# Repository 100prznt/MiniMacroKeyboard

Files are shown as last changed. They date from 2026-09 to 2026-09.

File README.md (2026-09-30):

# Mini Macro Keyboard (Raspberry Pi Pico)






Eine kleine USB-Makro-Tastatur auf Basis eines Raspberry Pi Pico, programmiert in
CircuitPython. Der Pico meldet sich am PC als Composite-HID-Gerät (Tastatur +
Maus gleichzeitig) und macht auf einer selbstgebauten 3-Taster-Platine ein paar
wiederkehrende Eingaben und eine kleine Anwesenheitssimulation überflüssig.

Ein Windows-Companion-Programm in C# (`MacroKeyboardSync/`) läuft im Hintergrund
und meldet dem Pico über einen zweiten USB-CDC-Kanal Uhrzeit, die aktuell aktive
Anwendung und den Sperrstatus des PCs.

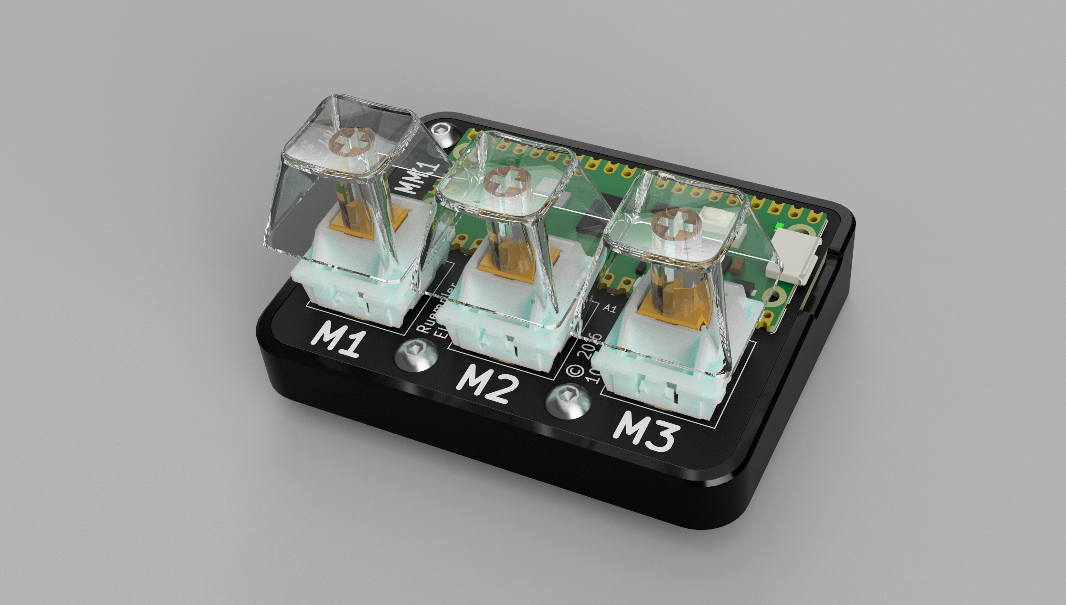
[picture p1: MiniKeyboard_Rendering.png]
MMK1 Rendering


## Funktionen

Die Platine hat drei Taster (M1–M3), alle gegen GND schaltend:

| Taste | Aktion |
|---|---|
| **M1** | Beim Loslassen: zweizeiliger TODO-Kommentar mit Name/Kürzel und aktuellem Zeitstempel, z. B. `// Mustermann, Max (MM/Abt1) 23.09.2026 10:23:34` gefolgt von einer leeren Kommentarzeile `// ` (Zeilenumbruch per Shift+Enter) |
| **M2** | Beim Loslassen: Text `M2` (Platzhalter, frei anpassbar) |
| **M3** | Kurzer Druck: gibt beim Loslassen die aktuell aktive Anwendung aus (siehe unten). Langer Druck (≥ 0,5 s): schaltet den Mausjiggler sofort um, ohne auf das Loslassen zu warten |
| **M1 + M3** (gleichzeitig) | Löscht per Backspace das letzte Zeichen im aktiven Feld, wartet kurz und gibt dann einen hinterlegten Text (`TEXT_M4`) + Enter aus – **nur** wenn entweder eine bestimmte Anwendung (in `code.py` festgelegt) im Vordergrund ist oder der PC gerade gesperrt ist. `M2` bleibt davon unbeteiligt |

**Mausjiggler:** Solange aktiv (Standard: direkt nach dem Einschalten), bewegt
sich der Mauszeiger alle 25 Sekunden minimal, um Bildschirmschoner/Abwesend-Status
(z. B. in Teams) zu verhindern. Die Onboard-LED pulsiert währenddessen in einem
Herzschlag-Muster (zwei Auf-/Abdimm-Pulse, kurze Pause, dann eine längere Pause).

**Status-LEDs:** Drei adressierbare RGB-LEDs (LTST-E683CEGBW) unter den Tastern,
in Reihe an GPIO18 über einen BSS138-Levelshifter angeschlossen, zeigen den
aktuellen Zustand an:
- **Aktive Anwendung:** alle drei LEDs leuchten in einer festen Farbe je nach
  `WIN:`-Tag – z. B. Lila für Visual Studio, Orange für KiCad, Grün für den
  KiCad-PCB-Editor, Rot für Opera, Weiß für den Explorer, Blau für Outlook/Teams,
  Lila für GitHub Desktop. Unbekannte Anwendungen zeigen ein gedimmtes Grau
  (`DEFAULT`).
- **VPN-Client aktiv:** die LEDs blinken abwechselnd Rot/Blau, wie ein
  US-Polizeiauto.
- **PC gesperrt:** rotes Lauflicht über die drei LEDs (Knight-Rider-/KITT-Effekt),
  zusätzlich gedimmt gegenüber den übrigen Zuständen. Hat Vorrang vor allen
  anderen Anzeigen.

Die Helligkeit aller Status-LEDs ist über die Konstante `MAX_BRIGHTNESS` in
`code.py` gedeckelt (Standard: 75 %).

**Sync mit dem PC:** Die Companion-App erkennt über die USB-Vendor-ID automatisch
den passenden COM-Port und sendet dem Pico:
- `TIME:` alle 5 Minuten (stellt die Software-RTC des Pico)
- `WIN:` bei jedem Wechsel der aktiven Anwendung (VS, VS Code, KiCad, KiCad-PCB-Editor,
  Opera, Explorer, Outlook, GitHub Desktop, Teams, VPN-Client – alles andere
  als `DEFAULT`)
- `LOCK:` bei Sperren/Entsperren sowie als Heartbeat alle 15 Sekunden, damit
  der Pico eine tote Verbindung erkennt

Ohne aktuelle Nachricht vom PC (z. B. direkt nach einem Neustart, bevor die
Companion-App läuft) geht der Pico sicherheitshalber von "gesperrt" aus.

## Hardware

- Raspberry Pi Pico
- Eigene Taster-Platine mit 3 Tastern gegen GND:
  - M1 → GPIO17
  - M2 → GPIO26
  - M3 → GPIO28
- 3x adressierbare RGB-LED LTST-E683CEGBW (in Reihe), Datenleitung an GPIO18
  über einen BSS138-Levelshifter

### CAD-Ansichten

| Von oben | Von rechts |
|---|---|
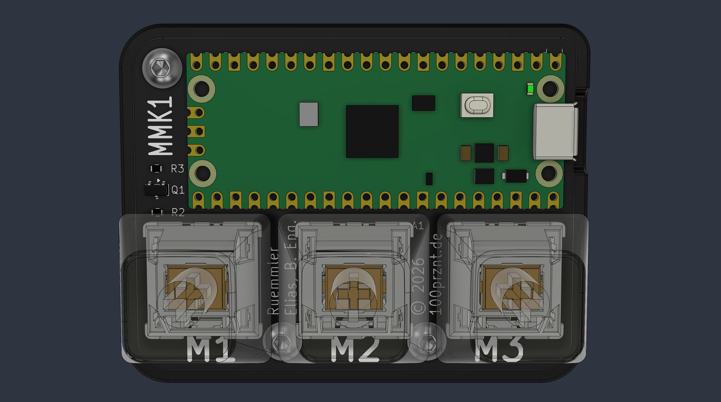
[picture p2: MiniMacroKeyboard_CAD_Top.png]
CAD-Ansicht von oben
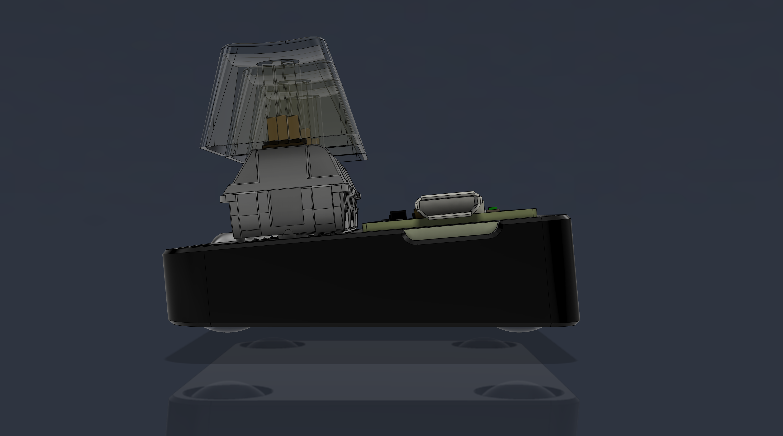
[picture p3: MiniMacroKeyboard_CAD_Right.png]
CAD-Ansicht von rechts
|  |  |

*Rechts:* Auf der Unterseite des 3D-gedruckten Rahmens sorgen 4 Gummipuffer für einen sicheren Stand.

### Erster Hardwareaufbau

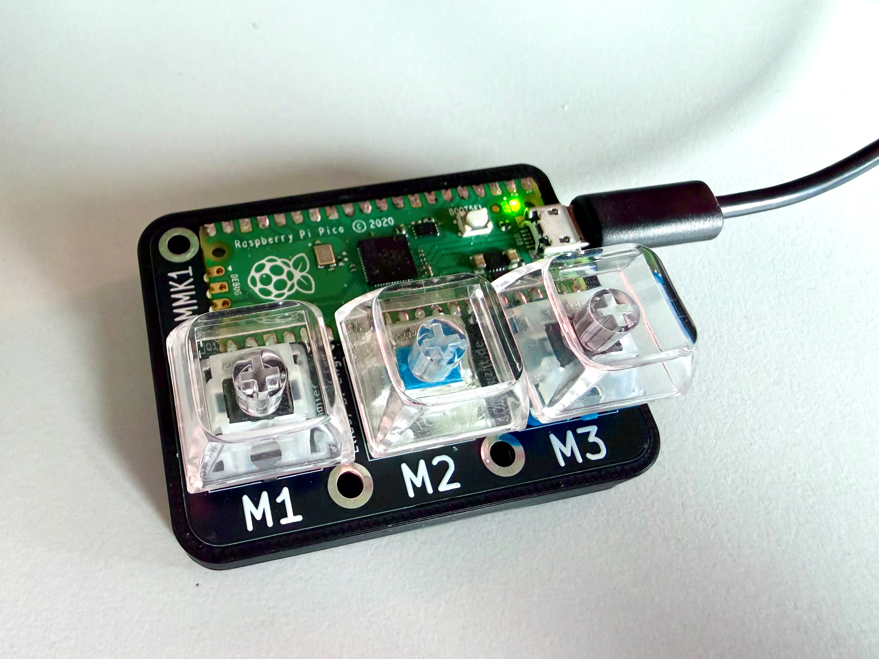
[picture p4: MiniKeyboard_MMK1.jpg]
Erster Hardwareaufbau


## Repo-Struktur

```
src/boot.py       Aktiviert den zweiten USB-CDC-Datenkanal (usb_cdc.data)
src/code.py       Hauptprogramm: Taster-Logik, HID-Ausgabe, Mausjiggler, Status-LEDs, Sync
src/macros.py.template  Vorlage fuer macros.py (TEXT_M2, TEXT_M4, TODO_SIGNATURE)
src/lib/          Benötigte CircuitPython-Bibliotheken (adafruit_hid, neopixel, dt. Tastaturlayout)
install/          CircuitPython-UF2 für den Pico (de_DE)
MacroKeyboardSync/ Windows-Companion-App (C#, .NET 8)
```

## Einrichtung (Pico)

1. [CircuitPython](https://circuitpython.org/board/raspberry_pi_pico/) auf den
   Pico flashen (die passende UF2-Datei liegt auch in `install/`).
2. Den Ordner `src/lib/` in den Ordner `lib/` auf dem `CIRCUITPY`-Laufwerk
   kopieren. Er enthält bereits alle benötigten Bibliotheken, sie müssen
   nicht separat heruntergeladen werden:
   - `adafruit_hid/` aus dem
     [Adafruit CircuitPython HID](https://github.com/adafruit/Adafruit_CircuitPython_HID)
   - `neopixel.mpy` aus dem
     [Adafruit CircuitPython Bundle](https://circuitpython.org/libraries)
     (steuert die drei Status-LEDs)
   - `keyboard_layout_win_de.py` und `keycode_win_de.py` (deutsches
     Tastaturlayout) aus
     [Neradoc/Circuitpython_Keyboard_Layouts](https://github.com/Neradoc/Circuitpython_Keyboard_Layouts)

   Die zugehörigen Lizenzen liegen als `LICENSE-*` daneben (beide MIT). Wer
   lieber aktuelle Versionen nutzt, kann sie stattdessen selbst aus dem
   [Adafruit CircuitPython Bundle](https://circuitpython.org/libraries) bzw.
   dem Neradoc-Repo holen.
3. `boot.py` und `code.py` aus `src/` auf das `CIRCUITPY`-Laufwerk kopieren.
4. `src/macros.py.template` nach `macros.py` kopieren (muss neben `code.py`
   liegen) und an die eigenen Texte anpassen (Name/Kürzel für M1, Text für
   die M1+M3-Combo). `macros.py` ist bewusst per `.gitignore` ausgeschlossen,
   damit persönliche Texte nicht versehentlich committet werden.

## Einrichtung (Companion-App)

1. `MacroKeyboardSync/` mit .NET 8 SDK bauen (`dotnet build` bzw. Visual
   Studio).
2. Die App beim Windows-Systemstart starten lassen (z. B. Autostart-Ordner
   oder Aufgabenplanung) – sie läuft ohne Konsolenfenster im Hintergrund.
3. Erkannte Anwendungen sind in der `KnownApps`-Dictionary in `Program.cs`
   hinterlegt und lassen sich dort um weitere Prozessnamen ergänzen. Läuft
   eine Anwendung (wie z. B. KiCad) bei dir komplett unter einem einzigen
   Prozess, wird in `GetActiveAppTag()` zusätzlich der Fenstertitel
   ausgewertet, um z. B. den PCB-Editor separat zu erkennen – Titeltext ggf.
   an die eigene Sprachversion anpassen.

## Hinweis zur M1+M3-Combo

Der bei `TEXT_M4` hinterlegte Text ist bei mir persönlich durch ein Passwort
ersetzt, das nur bei passender Anwendung bzw. gesperrtem PC getippt wird. Wer
das Repo als Vorlage nutzt: Der Wert liegt aktuell als Klartext in `macros.py`
auf dem Flash-Speicher des Pico – bei physischem Zugriff auf das Gerät ist er
auslesbar. Für den privaten Gebrauch an einem einzelnen, vertrauenswürdigen
Rechner ist das ein bewusst akzeptiertes Risiko, kein Ersatz für einen echten
Passwortmanager.

## Lizenz

Dieses Projekt steht unter der [MIT-Lizenz](LICENSE).

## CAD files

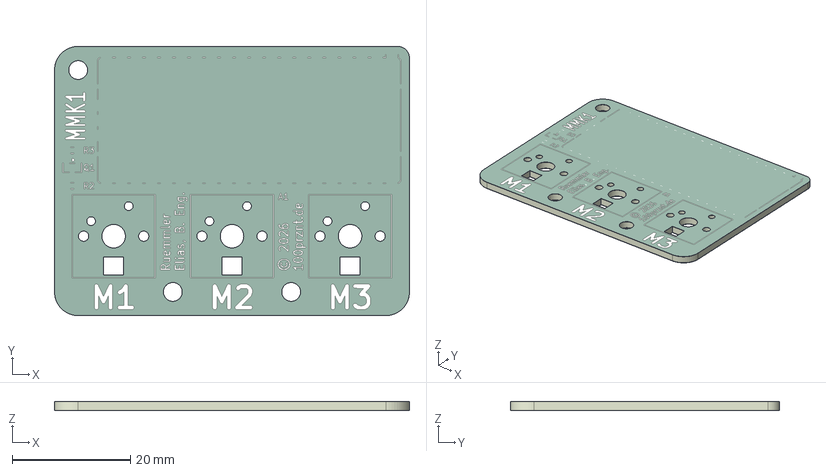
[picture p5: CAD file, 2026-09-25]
hardware/MiniMacroKeyboard/MiniMacroKeyboard.step
60.0 x 45.5 x 1.66 mm
Min7E8_silkscreen x 2
Min7E8_soldermask x 2
Min7E8_PCB

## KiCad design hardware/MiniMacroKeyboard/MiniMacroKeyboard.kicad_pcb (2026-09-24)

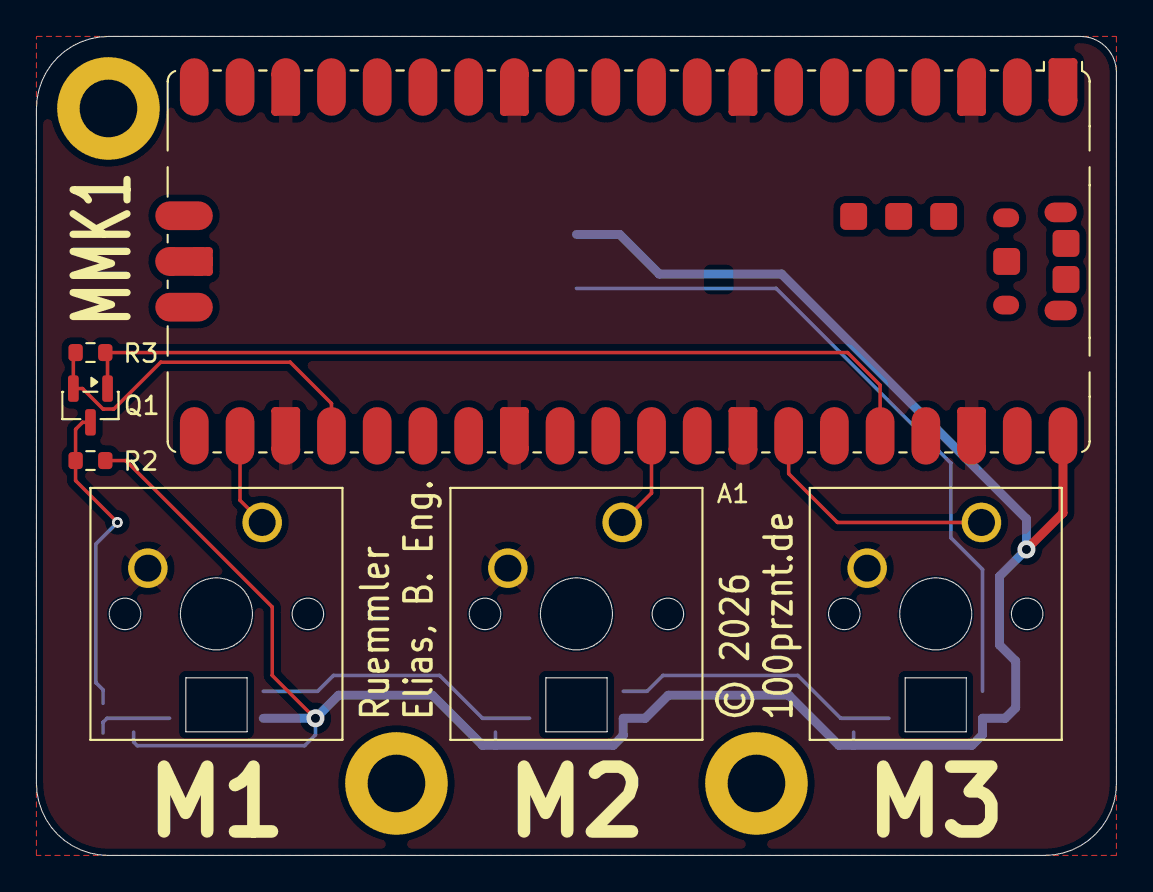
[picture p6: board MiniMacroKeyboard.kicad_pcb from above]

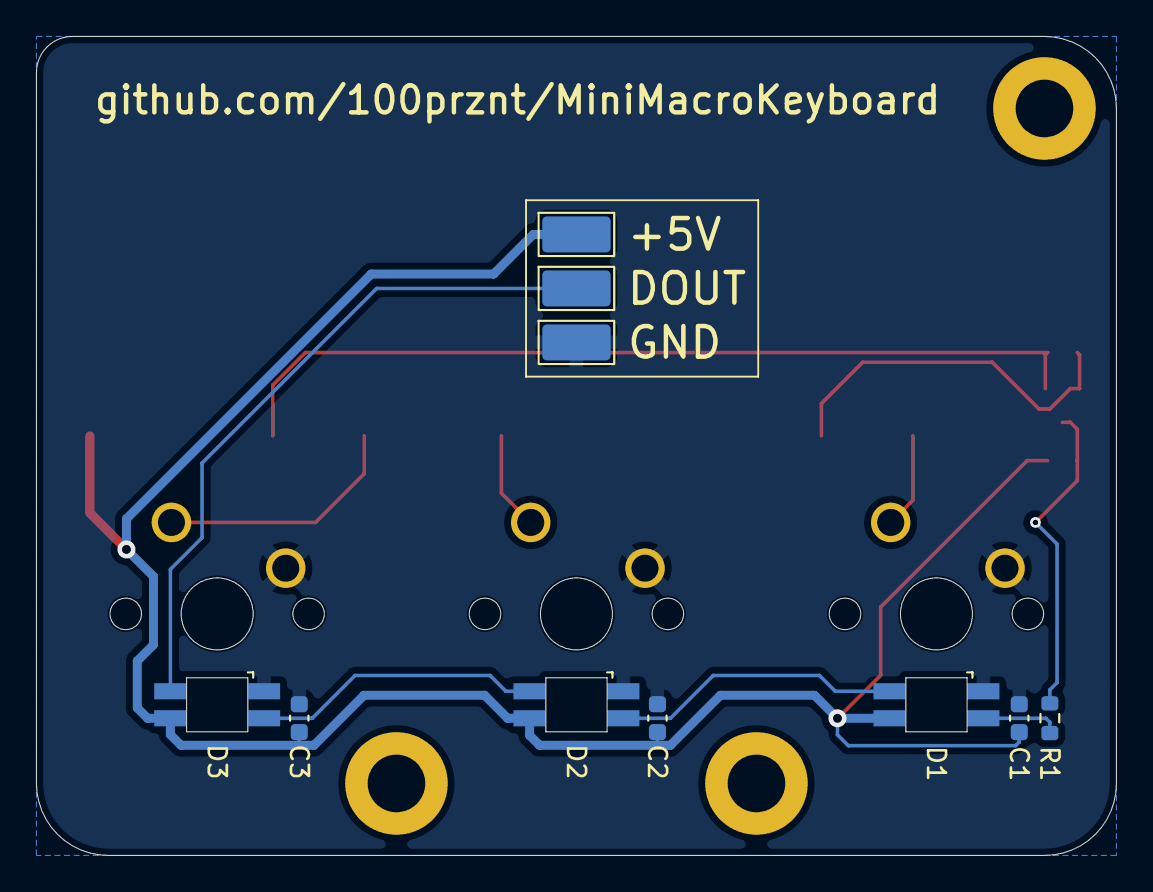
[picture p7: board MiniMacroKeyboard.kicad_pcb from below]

Board: 2 copper layers, 60.0 x 45.5 mm, 14 parts (7 on the bottom side), 12 nets.

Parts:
A1: RaspberryPi_Pico; RaspberryPi_Pico_SMD
C1, C2, C3: C; C_0603_1608Metric
M1, M2, M3: CherryMX_LTST-A683CEGBW; CherryMX_1.00u_PCB_LTST-A683CEGBW
Q1: BSS138; SOT-23
R1: 330R; R_0603_1608Metric
R2, R3: 10K; R_0603_1608Metric
TP1, TP2, TP3: TestPoint; TestPoint_Keystone_5019_Miniature

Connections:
+3.3V: A1.36 (3V3), Q1.1 (G), R3.2
+5V: A1.40 (VBUS), C1.1, C2.1, C3.1, M1.6 (VDD), M2.6 (VDD), M3.6 (VDD), R2.2, TP3.1 (1_1)
GNDD: A1.3 (GND), A1.8 (GND), A1.13 (GND), A1.18 (GND), A1.23 (GND), A1.28 (GND), A1.33 (AGND), A1.38 (GND), A1.D2 (GND), C1.2, C2.2, C3.2, M1.1, M1.3 (VSS), M2.1, M2.3 (VSS), M3.1, M3.3 (VSS), TP2.1 (1_1)
M1: A1.22 (GPIO17), M1.2
M2: A1.31 (GPIO26_ADC0), M2.2
M3: A1.34 (GPIO28_ADC2), M3.2
unnamed: A1.24 (GPIO18), Q1.2 (S), R3.1
unnamed: M1.4 (DIN), R1.1
unnamed: M1.5 (DOUT), M2.4 (DIN)
unnamed: M2.5 (DOUT), M3.4 (DIN)
unnamed: M3.5 (DOUT), TP1.1 (1_1)
unnamed: Q1.3 (D), R1.2, R2.1

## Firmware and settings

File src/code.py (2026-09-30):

import time
import board
import digitalio
import pwmio
import neopixel
import usb_hid
import usb_cdc
import rtc

from adafruit_hid.keyboard import Keyboard
from keyboard_layout_win_de import KeyboardLayout
from adafruit_hid.keycode import Keycode
from adafruit_hid.mouse import Mouse

from macros import TEXT_M2, TEXT_M4, TODO_SIGNATURE

kbd = Keyboard(usb_hid.devices)
layout = KeyboardLayout(kbd)
mouse = Mouse(usb_hid.devices)

# --- Taster-PCB: alle drei Taster schalten gegen GND ---
SWITCH_M1 = board.GP17
SWITCH_M2 = board.GP26
SWITCH_M3 = board.GP28

def make_switch(pin):
    io = digitalio.DigitalInOut(pin)
    io.direction = digitalio.Direction.INPUT
    io.pull = digitalio.Pull.UP   # gegen GND -> Pull-Up, gedrueckt = LOW
    return io

m1 = make_switch(SWITCH_M1)
m2 = make_switch(SWITCH_M2)
m3 = make_switch(SWITCH_M3)

# --- RGB-Status-LEDs: 3x LTST-E683CEGBW in Reihe an GPIO18 (ueber BSS138-Levelshifter) ---
# Alle drei LEDs zeigen gemeinsam die aktuell aktive Anwendung per Farbe an,
# ausser bei Sonderfaellen (VPN-Blinken, PC gesperrt -> Lauflicht).
# Falls die Farben vertauscht wirken, pixel_order=neopixel.RGB statt GRB testen.
LED_DATA_PIN = board.GP18
LED_COUNT = 3
MAX_BRIGHTNESS = 0.65   # 0.0-1.0, globale Helligkeitsgrenze fuer alle Status-LEDs

pixels = neopixel.NeoPixel(
    LED_DATA_PIN, LED_COUNT, brightness=MAX_BRIGHTNESS, auto_write=False,
    pixel_order=neopixel.RGB,
)

# Farbe je aktiver Anwendung (WIN:-Tag von der Companion-App, siehe check_serial())
APP_COLORS = {
    "VS":        (150, 0, 200),   # Visual Studio: kraeftiges Lila (wie das VS-Icon)
    "VSCODE":    (0, 122, 204),   # Visual Studio Code: Blau
    "KICAD":     (255, 80, 0),   # KiCad (Projektmanager/Schaltplan): Orange
    "KICAD_PCB": (40, 170, 0),    # KiCad PCB-Editor (Pcbnew): Gruen
    "OPERA":     (255, 0, 0),     # Opera: Rot
    "EXPLORER":  (255, 255, 255), # Explorer: Weiss
    "OUTLOOK":   (15, 15, 240),   # Outlook: Blau (wie das Outlook-Logo)
    "GITHUB":    (110, 0, 200),   # GitHub: Lila (wie das GitHub-Logo)
    "TEAMS":     (30, 50, 235),   # Teams: kraeftiges Blau (wie das Teams-Logo)
    "DEFAULT":   (20, 20, 20),
}

# VPN aktiv: rot/blau blinkend, wie ein US-Polizeiauto
VPN_FLASH_COLOR_A = (255, 0, 0)
VPN_FLASH_COLOR_B = (0, 0, 255)
VPN_FLASH_INTERVAL = 0.15    # Sekunden je Farbphase

# PC gesperrt: rotes Lauflicht (Knight-Rider/KITT-Scanner) ueber die 3 LEDs, gedimmt
LOCK_SCAN_COLOR = (255, 0, 0)
LOCK_SCAN_INTERVAL = 0.24          # Sekunden je Schritt
LOCK_SCAN_BRIGHTNESS = 0.4         # zusaetzliche Abdunklung des aktiven Pixels (relativ zu MAX_BRIGHTNESS)
LOCK_SCAN_TRAIL_BRIGHTNESS = 0.15  # Helligkeit der beiden Nachbar-Pixel (Lauflicht-Schweif)

def _scaled(color, factor):
    return tuple(int(c * factor) for c in color)

_last_led_state = None

def update_status_leds(now):
    global _last_led_state

    if pc_is_locked(now):
        # Knight-Rider-Scanner: ein Pixel wandert ueber die Kette, mit Schweif
        step = int(now / LOCK_SCAN_INTERVAL)
        ping_pong = (0, 1, 2, 1)
        pos = ping_pong[step % len(ping_pong)]

        colors = [(0, 0, 0)] * LED_COUNT
        colors[pos] = _scaled(LOCK_SCAN_COLOR, LOCK_SCAN_BRIGHTNESS)
        for neighbor in (pos - 1, pos + 1):
            if 0 <= neighbor < LED_COUNT:
                colors[neighbor] = _scaled(LOCK_SCAN_COLOR, LOCK_SCAN_TRAIL_BRIGHTNESS)
        state = ("lock", pos)

    elif active_window == "VPN":
        phase = int(now / VPN_FLASH_INTERVAL) % 2
        color = VPN_FLASH_COLOR_A if phase == 0 else VPN_FLASH_COLOR_B
        colors = [color] * LED_COUNT
        state = ("vpn", phase)

    else:
        color = APP_COLORS.get(active_window, APP_COLORS["DEFAULT"])
        colors = [color] * LED_COUNT
        state = ("app", color)

    if state != _last_led_state:
        for i, c in enumerate(colors):
            pixels[i] = c
        pixels.show()
        _last_led_state = state

# --- Onboard-LED: Herzschlag-Blinken via PWM, solange der Jiggler aktiv ist ---
led = pwmio.PWMOut(board.LED, frequency=1000, duty_cycle=0)

HEARTBEAT_FADE_IN = 0.3      # Sekunden pro Aufhellen
HEARTBEAT_FADE_OUT = 0.3     # Sekunden pro Abdunkeln
HEARTBEAT_GAP = 0.15         # Pause zwischen den zwei Pulsen eines "Herzschlags"
HEARTBEAT_PAUSE = 1.0        # Pause nach den zwei Pulsen, bevor es von vorn beginnt
HEARTBEAT_PULSE = HEARTBEAT_FADE_IN + HEARTBEAT_FADE_OUT
HEARTBEAT_CYCLE = 2 * HEARTBEAT_PULSE + HEARTBEAT_GAP + HEARTBEAT_PAUSE

def heartbeat_duty(t):
    # t: Sekunden seit Zyklusbeginn (0 .. HEARTBEAT_CYCLE)
    if t < HEARTBEAT_PULSE:
        pt = t
    elif t < HEARTBEAT_PULSE + HEARTBEAT_GAP:
        return 0
    elif t < 2 * HEARTBEAT_PULSE + HEARTBEAT_GAP:
        pt = t - (HEARTBEAT_PULSE + HEARTBEAT_GAP)
    else:
        return 0

    if pt < HEARTBEAT_FADE_IN:
        frac = pt / HEARTBEAT_FADE_IN
    else:
        frac = 1.0 - (pt - HEARTBEAT_FADE_IN) / HEARTBEAT_FADE_OUT

    frac = max(0.0, min(1.0, frac))
    return int(frac * 65535)

# --- USB-Serial-Datenkanal zur C#-Companion-App ---
serial = usb_cdc.data
active_window = "DEFAULT"

# Sicherer Default: bis der PC sich aktiv als "entsperrt" meldet, gilt er als gesperrt.
# Deckt Boot, Neustart und noch nicht laufende Companion-App ab.
pc_locked_reported = True
last_serial_received = 0.0          # time.monotonic()-Zeitpunkt der letzten Nachricht
LOCK_HEARTBEAT_TIMEOUT = 45.0        # Sekunden ohne Nachricht -> Verbindung gilt als tot -> gesperrt

def check_serial():
    global active_window, pc_locked_reported, last_serial_received
    if serial is None or serial.in_waiting == 0:
        return
    try:
        line = serial.readline().decode("utf-8").strip()
    except Exception:
        return

    last_serial_received = time.monotonic()

    if line.startswith("TIME:"):
        try:
            date_part, time_part = line[5:].split(" ")
            y, mo, d = map(int, date_part.split("-"))
            h, mi, s = map(int, time_part.split(":"))
            rtc.RTC().datetime = time.struct_time((y, mo, d, h, mi, s, 0, -1, -1))
        except Exception:
            pass

    elif line.startswith("WIN:"):
        active_window = line[4:]

    elif line.startswith("LOCK:"):
        pc_locked_reported = (line[5:] == "1")

def pc_is_locked(now):
    # Gesperrt, wenn entweder aktiv gemeldet, oder die Verbindung zu lange still war
    # (kein Heartbeat -> App laeuft nicht -> PC ist am Anmeldebildschirm o.ae.)
    if pc_locked_reported:
        return True
    return (now - last_serial_received) > LOCK_HEARTBEAT_TIMEOUT

def current_timestamp():
    now = time.localtime()
    return "{:02d}.{:02d}.{:04d} {:02d}:{:02d}:{:02d}".format(
        now.tm_mday, now.tm_mon, now.tm_year, now.tm_hour, now.tm_min, now.tm_sec
    )

def write_todo_comment():
    # Zeile 1: Kommentar mit Name/Kuerzel und Zeitstempel
    line1 = "// {} {}".format(TODO_SIGNATURE, current_timestamp())
    # Zeile 2: leere Kommentarzeile zum Weiterschreiben
    line2 = "// "

    layout.write(line1)
    # Zeilenumbruch als Shift+Enter (weicher Umbruch statt neuem Absatz)
    kbd.send(Keycode.SHIFT, Keycode.ENTER)
    layout.write(line2)

# --- Zustaende Taster (True = losgelassen, fuer Flankenerkennung) ---
last_m1 = True
last_m2 = True
last_m3 = True

# --- Combo-Erkennung M1+M3 -> "M4" + Enter, nur bei passender Anwendung oder gesperrtem PC ---
combo_active = False     # True, solange M1+M3 gemeinsam gehalten werden
m1_suppressed = False    # verhindert Text bei M1 beim Loslassen nach einer Combo
m3_suppressed = False    # verhindert M3-Kurz-/Lang-Logik nach einer Combo

# --- Kurz/Lang-Erkennung fuer M3 ---
LONG_PRESS_THRESHOLD = 0.5   # Sekunden
m3_press_start = None
m3_long_triggered = False

# --- Zustand Mausjiggler: startet bereits aktiv ---
jiggler_active = True
JIGGLE_INTERVAL = 25.0       # Sekunden zwischen den minimalen Mausbewegungen
last_jiggle = 0.0

while True:
    now = time.monotonic()

    check_serial()

    state_m1 = m1.value
    state_m2 = m2.value
    state_m3 = m3.value

    # --- Combo: M1 + M3 gleichzeitig gedrueckt -> "M4" + Enter,
    #     aber nur bei passender Anwendung oder gesperrtem PC ---
    if (not state_m1) and (not state_m3) and not combo_active:
        if active_window == "VPN" or pc_is_locked(now):
            kbd.send(Keycode.BACKSPACE)
            time.sleep(0.25)
            layout.write(TEXT_M4)
            kbd.send(Keycode.ENTER)
        combo_active = True
        m1_suppressed = True
        m3_suppressed = True
        m3_press_start = None
        m3_long_triggered = True   # unterdrueckt die spaetere Lang-Druck-Auswertung

    if state_m1 and state_m3:
        # beide wieder losgelassen -> Combo-Sperre aufheben
        combo_active = False

    # --- M1: TODO-Kommentar mit Zeitstempel erst beim Loslassen, ausser bei Combo (Testbelegung) ---
    if (not last_m1) and state_m1:
        if not m1_suppressed:
            write_todo_comment()
        m1_suppressed = False
    last_m1 = state_m1

    # --- M2: Text erst beim Loslassen (unbeteiligt an der Combo) ---
    if (not last_m2) and state_m2:
        layout.write(TEXT_M2)
    last_m2 = state_m2

    # --- M3: kurz -> aktive Anwendung beim Loslassen (Testbelegung),
    #          lang -> Jiggler sofort beim Ueberschreiten des Thresholds umschalten ---
    if last_m3 and not state_m3:
        # Flanke: losgelassen -> gedrueckt
        if not combo_active:
            m3_press_start = now
            m3_long_triggered = False

    elif not state_m3 and m3_press_start is not None and not m3_long_triggered and not m3_suppressed:
        # Taste wird weiterhin gehalten -> Haltedauer pruefen, ohne auf Loslassen zu warten
        if now - m3_press_start >= LONG_PRESS_THRESHOLD:
            jiggler_active = not jiggler_active
            m3_long_triggered = True

    elif (not last_m3) and state_m3:
        # Flanke: gedrueckt -> losgelassen
        if not m3_long_triggered and not m3_suppressed:
            layout.write(active_window)
        m3_press_start = None
        m3_long_triggered = False
        m3_suppressed = False

    last_m3 = state_m3

    # --- Mausjiggler-Logik ---
    if jiggler_active:
        led.duty_cycle = heartbeat_duty(now % HEARTBEAT_CYCLE)
        if now - last_jiggle >= JIGGLE_INTERVAL:
            mouse.move(x=1)
            mouse.move(x=-1)
            last_jiggle = now
    else:
        led.duty_cycle = 0

    update_status_leds(now)

    time.sleep(0.01)

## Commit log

2026-09-23 LOCK-Heartbeat alle 15 s senden
    Der Pico wertet >45 s ohne Nachricht als gesperrt; bisher wurde LOCK nur
    bei Statusaenderung gesendet, sodass ein entsperrter PC faelschlich als
    gesperrt galt.
2026-09-23 AppVeyor: win-x64 Publish und GitHub-Release bei Tags
2026-09-23 AppVeyor: neuer Token, Release-Tag und Prerelease-Flag
2026-09-23 Bibliotheken in src/lib, Build-Version aus Tag, KiCad-Ignore
2026-09-24 add kicad project
    [MiniMacroKeyboard.kicad_pcb, MiniMacroKeyboard.kicad_sch]
2026-09-25 Add cad rendering
    [MiniMacroKeyboard.step]
2026-09-25 macros.py aus dem Repo entkoppeln, Aufräumen von .lck-Dateien und Foto
    - src/macros.py durch src/macros.py.template ersetzt (muss vor dem
    Kopieren auf den Pico zu macros.py umbenannt werden). Damit landet
    eine spätere lokale Anpassung (z.B. ein bei TEXT_M4 hinterlegtes
    Passwort) nicht versehentlich im Repo, obwohl macros.py schon per
    .gitignore ausgeschlossen war - die Datei war trotzdem getrackt,
    weil .gitignore für bereits verfolgte Dateien nicht greift.
    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
2026-09-25 README: CAD-Ansichten (Top/Right) ergänzen
2026-09-25 README: Hinweis zu den Gummipuffern bei der CAD-Right-Ansicht
2026-09-25 upd images cad
2026-09-25 README: Tabellenüberschriften der CAD-Ansichten auf Deutsch
2026-09-30 Implement RGB status LEDs with neopixel support
    Added RGB status LEDs functionality with neopixel support, including color definitions for active applications and behaviors for locked PC and VPN states.
2026-09-30 Enhance README with button and LED details
    Updated README with detailed descriptions of button functionalities, status LEDs, and repository structure.

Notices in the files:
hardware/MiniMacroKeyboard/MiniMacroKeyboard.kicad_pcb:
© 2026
